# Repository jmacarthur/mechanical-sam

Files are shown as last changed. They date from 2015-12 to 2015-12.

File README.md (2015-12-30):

# Mechanical SAM

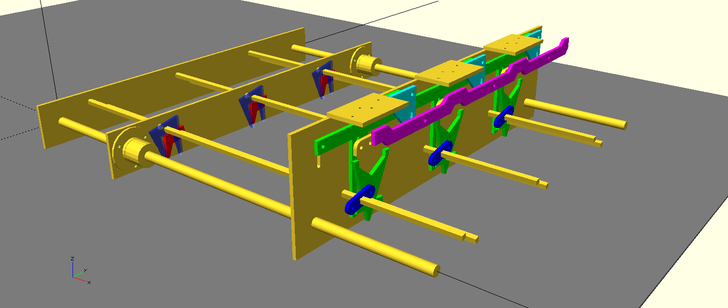
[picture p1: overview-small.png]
Drawing of SAM module


Mechanical, binary, sequential-access memory. Shown in this image is a 3 bit x approximately 30 word memory.

Please note that this design is not complete and has not been constructed yet.

# Priniciple of operation

The memory is based on perforated steel sheet, on which 4mm diameter ball bearings are placed. A single ball bearing is either in the '0' or '1' position to record memory values. No ball bearings are added to or removed from the sheet.

There is a pair of lead screws which move the read head across this sheet; this read head will then read 3 bits of data at a time and present the results on bowden cables. It is sequential access memory (SAM) meaning that you can only move to the memory location one space forward or backwards from the current one. There is no index or record of the current position inside the memory itself.

# To do

* Add the reverse gear and differential drive to the lead screws.
* Add a timing pulley to each leadscrew with a belt between them to keep them synchronised.
* Test the movement of the read output bar.
* Add some means to automatically centre the write bar before movement.
* Add bearings wherever any rotating parts meet. To run square rods in a round hole, it may be necessary to make sleeves which adapt them to round shapes which will then sit in a ball bearing.

# How to operate the memory

There are six boolean inputs to the memory: Three data lines, one for each bit to be written, a direction line, a drive enable bit, and a read enable bit. Each of these is expected to have two bowden cable lines, one for each value. There's also a continuous rotating shaft needed to actually rotate the lead screws.

I'll assume a cycle starts with the memory at rest; the read head is positioned exactly over a data word. At this point, your logic should already have update the write lines to alter the data in the current cell. The direction bit should also be set up. Read enable should be off. The write lines should be set to neutral, i.e. halfway between 1 and 0.

You should then assert drive enable for exactly 13 revolutions of the main drive shaft. During this time, the lead screws will rotate 4 and one third revolutions; the 2mm pitch on the screw will move the read head on 8.66mm in either direction.

Drive enable should then be turned off, and read enable should be cycled on and off. This will set up the read lines. All the read lines are powered from the read enable line, so you must have sufficient force applied to overcome the loading of whatever your read lines are connected to.

There is currently no protection against seeking past the end of the data in either direction.

# Future improvements

There is enough space on the grid to fit five bits of data in, with two rows inside the existing three. There isn't enough space on the front panel to read that data out, but you could have a second front panel with staggered readers in front of the existing panel, or a panel at the other end of the reader.

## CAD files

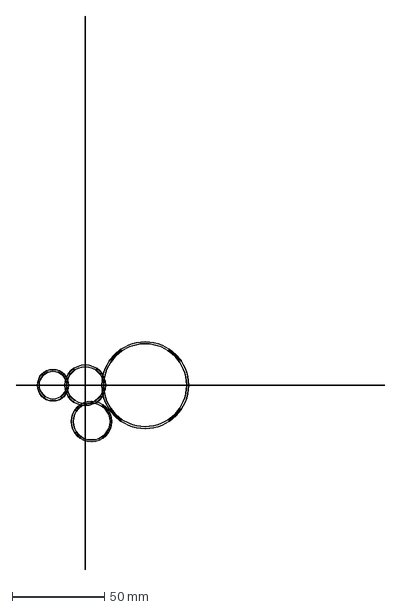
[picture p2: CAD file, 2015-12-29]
reverse-gear.dxf
200.0 x 300.0 mm

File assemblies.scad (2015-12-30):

include <globals.scad>
barHoleRadius = sqrt(2*2+2*2);
outputDriveOffset = 15; // Amount drive slots (top of output bar) are offset from the toggles they drive below

$fn=20;

module SupportPlate2D()
{
  difference() {
    translate([-20,-20]) square([300+40,40]);
    for(bit=[0,1,2]) {
      // Holes for write rods.
      translate([bit*bitSpacing+bit0Y,10]) circle(r=barHoleRadius);
      // Holes for read rods.
      translate([bit*bitSpacing+bit0Y+30+readHeadAdjustY,0]) circle(r=barHoleRadius);
    }
    // Holes for leadscrews.
    translate([0,0]) cylinder(r=4);
    translate([300,0]) cylinder(r=4);
  }
}

module SupportPlate() 
{
  rotate([90,0,90]) linear_extrude(height=3) SupportPlate2D();
}

module ReadWriteHead()
{
  SupportPlate();
  //color([1.0,1.0,0.0,0.5]) translate([12,0,0]) SupportPlate();
  for(bit=[0,1,2]) {
    translate([4,bit*bitSpacing+bit0Y+30+readHeadAdjustY,0]) rotate([readBarRotate,0,0]) ReadHead();
    translate([8,bit*bitSpacing+bit0Y,10]) WriteHead();
  }
}

module ReadHead2D() 
{
  difference() {
    translate([-5,-5])
    polygon(points= [[0,0], [20,0], [24,20], [21,20], [15,10], [0,10]], paths = [[0,1,2,3,4,5]]);
    translate([-2,-2]) square(size=[4,4]);
  }
}

module ReadHead()
{
  color([1.0,0.0,0.0]) rotate([-90,0,0]) rotate ([0,90,0]) linear_extrude(height=3) ReadHead2D();
}

module WriteHead2D() 
{
  difference() {
    translate([0,0])
      polygon(points= [[-15,-5], [15,-5], [9,28], [6,30], [6,5], [-6,5], [-6,30], [-9,28]], paths = [[0,1,2,3,4,5,6,7]]);
    translate([-2,-2]) square(size=[4,4]);
  }
}

module WriteHead()
{
  color([0.0,0.1,1.0,0.5]) rotate([-90+writeBarRotate,0,0]) rotate ([0,90,0]) linear_extrude(height=3) WriteHead2D();
}

module EndPlate() 
{
  SupportPlate();
}

module WriteBowdenPlate()
{
  difference() {
    cube([30,50,3]);
    translate([3+15,5,-thin]) cylinder(r=1, h=3+2*thin);
    translate([3+15,25,-thin]) cylinder(r=1, h=3+2*thin);
    translate([3+9,20,-thin]) cylinder(r=1, h=3+2*thin);
    translate([3+9,40,-thin]) cylinder(r=1, h=3+2*thin);
  }
}


module FrontPanel2D()
{
  difference() {
    union() {
      SupportPlate2D();
      translate([-20,20-thin]) square([300+40,50]);
    }
    for(x=[5,300-5]) {
      translate([x,40]) circle(r=1.5);
      translate([x,55]) circle(r=1.5);
      translate([x-1.5,40]) square([3,15]);
    }
    // Holes for crank axles
    translate([0,bit0Y,0]) for(bit=[0,1,2,3]) {
      translate([bit*bitSpacing+60+25+outputDriveOffset,35]) circle(r=1.5);
    }
  }
}

module FrontPanel()
{
  union(){
    rotate([90,0,90]) linear_extrude(height=3) FrontPanel2D();
    //translate([27,0,0]) rotate([90,0,90]) linear_extrude(height=3) FrontPanel2D();
    for(bit=[0,1,2]) 
      translate([0, bit*bitSpacing+bit0Y+readHeadAdjustY, 70])  WriteBowdenPlate();
  }
}


module ReadToggle2D()
{
    difference() {
      rotate(-14.5) { // Adjust this so it's halfway into the range of rotation of the read head
	union() {
	  polygon(points=[[-35,-20], [-35,-15], [-30,-15], [-20,0], [-30,15], [-35,15], [-35,20], [15,1], [15,-1]], paths = [[0,1,2,3,4,5,6,7,8]]);
	  translate([-0,-15]) square([5,30]); // Travel lifting bar
	}
      }
      translate([-2,-2]) square([4,4]);
    }
}

module ReadToggle()
{
  color([0,1.0,0]) rotate([0,90,0]) linear_extrude(height=3) ReadToggle2D();
}

module WriteToggle2D()
{
  difference() {
    union() {
      translate([0,-10]) circle(r=5);
      translate([0,10]) circle(r=5);
      translate([-5,-10]) square([10,20]);
    }
    translate([-2,-2]) square([4,4]);
    translate([0,-10]) circle(r=1.5);
    translate([0,10]) circle(r=1.5);
  }
}

module WriteToggle()
{
  color([0,0,1.0]) translate([6,0,0]) rotate([0,90,0]) linear_extrude(height=3) WriteToggle2D();
}

module ReadOutputBar2D()
{
  difference() {
    union() {
      square([10,300]);
      // Extensions for drive slots
      translate([0,bit0Y]) for(bit=[0,1,2]) {
	translate([-10,bit*bitSpacing-5+30+outputDriveOffset]) square([10,20]);
	translate([0,bit*bitSpacing-5+30+readHeadAdjustY])square([20,10]);
	translate([5,bit*bitSpacing-2.5+30+readHeadAdjustY-10])square([65,5]);
      }
    }
    translate([0,bit0Y]) for(bit=[0,1,2]) {
      // Holes for toggles 
      translate([15,bit*bitSpacing+30+readHeadAdjustY]) circle(r=1.5);
      // Hole for transit read raiser pin
      translate([66,bit*bitSpacing+30+readHeadAdjustY-10]) circle(r=1.5);
    }
    // Dowel holes at each end for slots
    translate([5,5]) circle(r=1.5);
    translate([5,300-5]) circle(r=1.5);
    // Drive slots
    translate([0,bit0Y]) for(bit=[0,1,2]) {
      translate([-5,bit*bitSpacing+30+outputDriveOffset]) circle(r=1.5);
      translate([-5-1.5,bit*bitSpacing+30+outputDriveOffset]) square([3,10]);
      translate([-5,bit*bitSpacing+30+10+outputDriveOffset]) circle(r=1.5);
    }
  }
}


module OutputCrank2D()
{
  difference() {
    union() {
      polygon(points=[[0,0], [30,0], [30,-30], [20,-30], [0,-10]], polys=[[0,1,2,3,4]]);
    }
    translate([5,-5]) circle(r=1.5);
    translate([25,-5]) circle(r=1.5);
    translate([25,-25]) circle(r=1.5);
    translate([25,-20]) circle(r=1.5);
    translate([25-1.5,-25]) square([3,5]);
    
  }
}

module DriveBar2D()
{
  difference() {
    union() {
      for(bit=[0,1,2]) {
	translate([bit*bitSpacing,0]) polygon(points=[[0,5], [10,5], [15,0], [bitSpacing-5,0], [bitSpacing,5], [bitSpacing, 15], [bitSpacing-10,15], [bitSpacing-15,10], [20,10], [15,15],[0,15]
						      ], polys=[[0,1,2,3,4,5,6,7,8,9,10]]);
      }
    }
    for(bit=[0,1,2]) {
      translate([bit*bitSpacing+45+outputDriveOffset,5]) circle(r=1.5);
    }
  }
}

module OutputToggle2D()
{
  difference() {
    union() {
      translate([-10,0]) circle(r=5);
      translate([10,0]) circle(r=5);
      translate([-10,-5]) square([20,10]);
      translate([-15,-5]) square([30,5]);
    }
    for(x=[-10,0,10]) {
      translate([x,0]) circle(r=1.5);
    }
  }
}

module ReadOutputBar()
{
  color([0,1.0,0]) rotate([0,90,0]) linear_extrude(height=3) ReadOutputBar2D();
  //color([0,1.0,0]) translate([21,0,0]) rotate([0,90,0]) linear_extrude(height=3) ReadOutputBar2D();
  translate([0,bit0Y,0]) for(bit=[0,1,2]) {
    color([0.0,1.0,1.0]) translate([3,bit*bitSpacing+30+outputDriveOffset,10]) rotate([90,0,90]) linear_extrude(height=3) OutputCrank2D();
    //color([0.0,1.0,1.0]) translate([18,x-30+outputDriveOffset,10]) rotate([90,0,90]) linear_extrude(height=3) OutputCrank2D();
    translate([6,bit*bitSpacing+30+readHeadAdjustY,-15]) rotate([90,0,90]) linear_extrude(height=3) OutputToggle2D();
  }
  translate([15,bit0Y+10,-17.5]) color([1.0,0.0,1.0]) rotate([90,0,90]) linear_extrude(height=3) DriveBar2D();
}

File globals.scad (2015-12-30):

thin = 0.01;

readBarRotate = 10; // Min 10, Max 20ish?
writeBarRotate = 12; // +/- 12 degrees; should be zero to move.

readHeadAdjustY = -13;

// Grid: RS stock no 817448, confirmed by measurement                                                                                                 
gridPitch = 5;
holeDiameter = 3;
gridThickness = 0.7;
gridSpacingY = gridPitch*sin(60);
gridSpacingX = gridPitch;

// Ball bearings. Available from simplybearings.co.uk.
bbDiameter= 4;

// Calculated stuff
bbRadius = bbDiameter / 2;
halfHoleDiameter = holeDiameter / 2;
bbHeight = sqrt(bbRadius*bbRadius - halfHoleDiameter * halfHoleDiameter);

//        /|\                                                                                                                                       
//       / | \                                                                                                                                      
//      /  |  \ bbRadius                                                                                                                            
//     /   |   \                                                                                                                                    
//    /    |    \                                                                                                                                   
//   /     |a    \  a=bbHeight                                                                     
//  /      |      \                                                                                                                                  
//  <------------->                                                                                                                 
//  holeDiameter     

// If bb centres are at zero height, then the grid starts at height bbHeight - bbRadius


bit0Y = 30; // Y pos, centre of write axis (mid-way Y between the two states)
bitSpacing = 100;

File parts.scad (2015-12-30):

include <globals.scad>

// Leadscrew nut. This is a Rondo ball screw nut, from:
// http://www.mooreinternational.co.uk/category-24/RONDO8x2.html

l2 = 3;
l3 = 5;
l4 = 25;

module LeadScrewNut()
{
  difference() {
    union() {
      cylinder(r=10.25,h=l4);
      cylinder(r=10.5, h = l2+l3);
      cylinder(r=19,h=l3);
    }
    rotate([0,0,120]) translate([29/2,0,-thin]) cylinder(r=1.5, h=l3+2*thin);
    rotate([0,0,240]) translate([29/2,0,-thin]) cylinder(r=1.5, h=l3+2*thin);
    rotate([0,0,000]) translate([29/2,0,-thin]) cylinder(r=1.5, h=l3+2*thin);
    translate([0,0,-thin]) cylinder(r=4, h=l4+2*thin);
  }
}

module LeadScrew()
{
  cylinder(r=4, h=400);
}

// Other parts, not modelled:

/* Hexagon pattern perforated steel sheet:
   http://uk.rs-online.com/web/p/perforated-steel-sheets/0817448
   When used as a rectangular grid, it's 5mm between the spaces on the 
   short axis, and 8.666mm between spaces on the long axis.
   Hexagon grid is used because no appropriate square pattern grid exists. */

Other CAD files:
toplevel.scad

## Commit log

2015-12-25 Add schematic diagram
2015-12-27 Add lots of SCAD files
    [assemblies.scad, globals.scad, parts.scad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]
2015-12-27 Read/write levers
    [assemblies.scad, toplevel.scad]
2015-12-28 Read output bar, bars and toggles
    [assemblies.scad, parts.scad, toplevel.scad]
2015-12-28 Add more bits to output bar
    [assemblies.scad]
2015-12-28 Convert support plates to 2D model
    [assemblies.scad]
2015-12-28 Add slots to front panel to guide the output bar
    [assemblies.scad]
2015-12-28 Drive bar and cranks
    [assemblies.scad]
2015-12-29 Add reverse gear diagram and specifications
    [reverse-gear.dxf]
2015-12-29 Rearrange cranks out of way of output toggles
    [assemblies.scad, toplevel.scad]
2015-12-29 More rearrangements
    [assemblies.scad, toplevel.scad]
2015-12-29 Add readBarRotate
    [assemblies.scad, toplevel.scad]
2015-12-29 Move read axis closer to data
    [assemblies.scad, toplevel.scad]
2015-12-29 Write bar rotate
    [assemblies.scad, toplevel.scad]
2015-12-29 Read head adjust Y
    [assemblies.scad, globals.scad, toplevel.scad]
2015-12-29 Read head adjust Y (fixup)
    [globals.scad]
2015-12-29 New-style read toggle
    [assemblies.scad, globals.scad, toplevel.scad]
2015-12-29 Adjustments to bowden cable plate
    [assemblies.scad, toplevel.scad]
2015-12-29 Correction to crank holes in front panel
    [assemblies.scad]
2015-12-29 Slight rearrangement of output toggles
    [assemblies.scad, globals.scad, toplevel.scad]
2015-12-29 More Bowden cable mounts and the ability to duplicate the front panel
    [assemblies.scad]
2015-12-29 More rearrangement, and duplicated some elements
    [assemblies.scad]
2015-12-30 Define all bit elements in terms of bit0Y
    [assemblies.scad, globals.scad, toplevel.scad]
2015-12-30 Now mostly respects bitSpacing (except drive bar)
    [assemblies.scad, globals.scad, toplevel.scad]
2015-12-30 Some corrections to the drive bar for bitSpacing
    [assemblies.scad, globals.scad, toplevel.scad]
2015-12-30 More correctiosn to the drive bar
    [assemblies.scad, globals.scad]
2015-12-30 Extra holes per bit, read/write heads per, move Bowden plate up
    [assemblies.scad]
2015-12-30 Add perforated sheets detail to parts.scad
    [parts.scad]
